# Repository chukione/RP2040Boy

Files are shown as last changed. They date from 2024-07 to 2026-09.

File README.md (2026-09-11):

# ~~Arduino~~RP2040boy
~~Official~~ ArduinoBoy port to RP2040 uC, its cheapear than a avr uC, it have so much more ram than a avr. The available boards come with megabytes of flash space, making ideal to use a oled display instead of the leds array.

On the breadboard photo, im using a transistor and a led, but is removed on the schematic because is a non sense. In original code (what i left untouched), the optoisolator is powered without condition on setup() 

USB midi with TynyUSB lib, and serial midi work.

At the moment, the only tested mode is mGB. LSJD midiout via usb is broken (serial must work, but its disabled.)

I normaly use linux, the dependencies and the pico toolchain is installed automacally on vscode with platformio extension, but on windows, you need to enable long paths on both git, and windows as described [here](https://arduino-pico.readthedocs.io/en/latest/platformio.html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). On arduino ide, you need to add the Earle Philhower core as described [here](https://learn.adafruit.com/rp2040-arduino-with-the-earlephilhower-core/installing-the-earlephilhower-core), also need to add the u8g2 library and the forty seven effects midi library and select the tinyusb usb stack on the menu.

rp4020boy_case
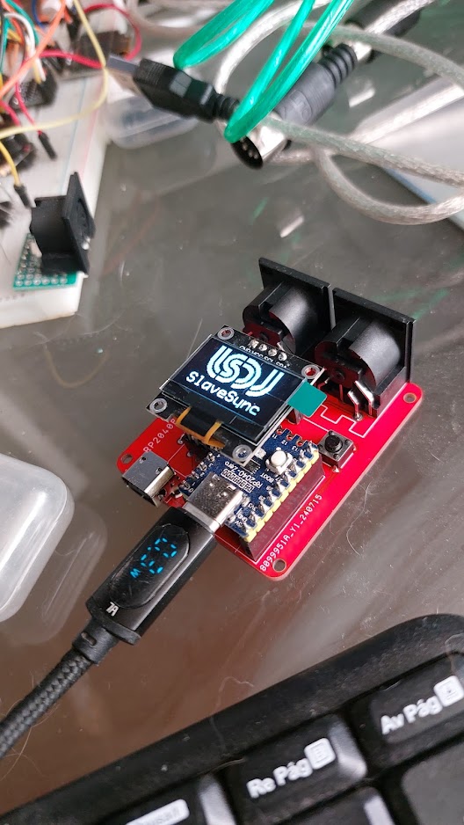
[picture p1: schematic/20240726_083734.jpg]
rp4020boy_pcb

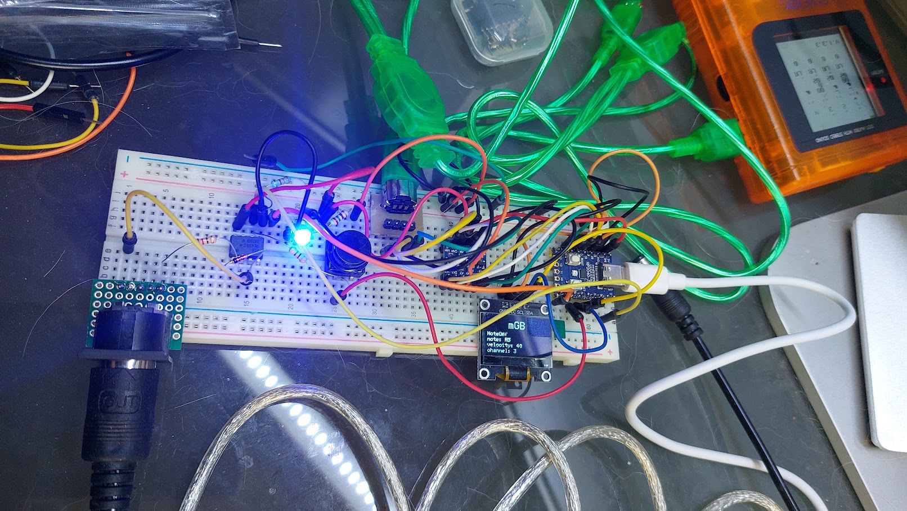
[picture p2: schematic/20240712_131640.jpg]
rp4020boy


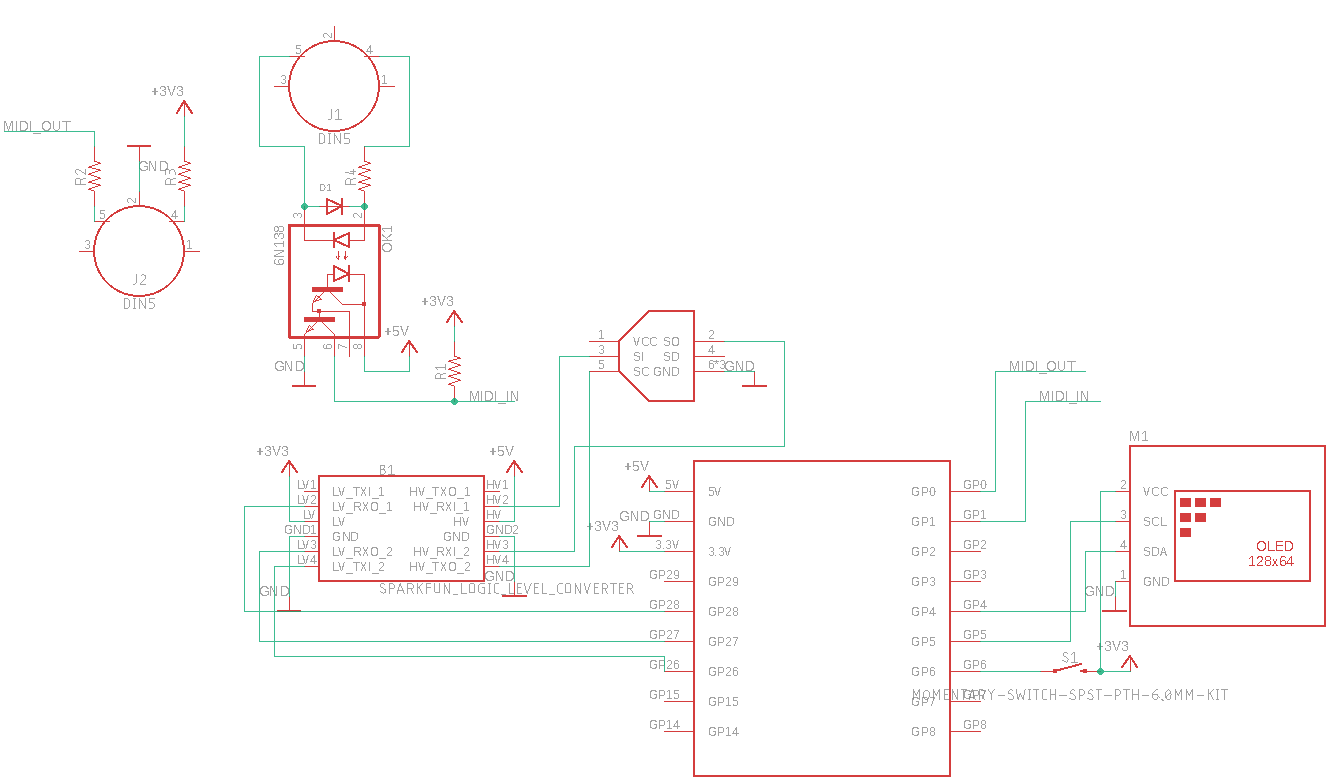
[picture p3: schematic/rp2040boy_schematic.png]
schematic


Repository for serial MIDI communication to the Nintendo Gameboy.



## About 
Arduinoboy is software for the [Arduino hardware platform](http://arduino.cc) that allows serial communication (MIDI) to the Nintendo Gameboy for music applications such as [LittleSoundDJ](http://littlesounddj.com), [Nanoloop.](http://www.nanoloop.com/), and [mGB](https://github.com/trash80/mGB)

## Current Features
* Affordable and easily accessible parts for assembly.
* Accurate MIDI Sync, Start and Stop commands.
* Push Button selector sets the sync/state modes [(7 modes available)](#modes-details)
* [mGB](https://github.com/trash80/mGB)
 Mode: Full MIDI in support across all Gameboy Channels, including a unique "poly" mode allows you to play your Game Boy like a synthesizer. 
* Midi Out Doubles as a Midi Thru
* "Filtering" data for only sync messages, no dedicated MIDI line required.
* Can be powered by the Game Boy's gamelink port.
* USB upgradeable via Arduino.
* Midi settings configurable using a Mac/PC editor built in Max.
* Tested and works with DMG (Original), Gameboy Color, and Advance/SP.

## Modes Details
#### Mode 1 - LSDJ as MIDI Slave Sync
Slave your Game Boy running [LittleSoundDJ](http://littlesounddj.com) to your midi sequencer or Digital audio workstation.  

You can send the arduinoboy midi notes to change sync resolution and start/stop the LSDJ sequencer.  

_LSDJ Slave Mode Midi Note Effects:_

* 48 - `C-2` Sends a Sequencer Start Command
* 49 - `C#2` Sends a Sequencer Stop Command
* 50 - `D-2` Toggles Normal Tempo 
* 51 - `D#2` Toggles 1/2 Tempo
* 52 - `E-2` Toggles 1/4 Tempo
* 53 - `F-2` Toggles 1/8 Tempo

Higher note values than these map LSDJ song position row offset on a Song Start.

In LSDJ the `sync` mode should be set to `Slave`
 
#### Mode 2 LSDJ as MIDI Master Sync. 

Send Midi sync with LSDJ as a midi clock master, LSDJ also sends a Midi Note on message that corresponds to the song row number on play.

In LSDJ the `sync` mode should be set to `Master`

#### Mode 3 LSDJ PC Keyboard mode.
This mode emulates the [PC Keyboard Mode](http://littlesounddj.wikia.com/wiki/PC_Keyboard_Interface) built into LSDJ, allowing you to control the following aspects of LSDJ: 

Features:

* The first octave controls M-U-T-E, 
* Cursor control (LSDJ Live mode only), 
* Table selection
* Table cue.

_PC Keyboard mode midi note map_

* 36 - `C-1` Mute Pu1 Off/On
* 37 - `C#1` Mute Pu2 Off/On
* 38 - `D-1` Mute Wav Off/On
* 39 - `D#1` Mute Noi Off/On
* 40 - `E-1` Livemode Cue Sequence
* 41 - `F-1` Livemode Cursor Up
* 42 - `F#1` Livemode Cursor Down
* 43 - `G-1` Livemode Cursor Left
* 44 - `G#1` Live mode Cursor Right
* 45 - `A-1` Table Up
* 46 - `A#1` Table Down
* 47 - `B-1` Cue Table
* 48+ - Notes from this note up will accept midi in from an external keyboard or sequencer and allow you to play the notes`C-2 to C-8`.  
* Midi Program Change messages will select from instrument table
* Default Midi channel is 16. You can set this in the top of the main source file in the archive, or via the [Max Pat editor](#max).

In LSDJ the `sync` mode should be set to `Keyboard`

#### Mode 4 MIDI to Nanoloop sync
Sync [Nanoloop.](http://www.nanoloop.com/) to external midi clock signals sent to the midi in.

In Nanoloop, the sync mode should be set to `slave`.

#### Mode 5 Full MIDI with mGB
[mGB](https://github.com/trash80/mGB) is a Gameboy cartridge program (You need a Flash Cart and Transfer hardware) That enables the Gameboy to act as a MIDI supported sound module that allows full control of the Game Boy sound hardware. 

It works with the old DMG Gameboy as well as GBC/GBA.

#### Mode 6 LSDJ MIDIMAP 
Lsdj will sync to incoming MIDI sync, and incoming MIDI notes are mapped to LSDJ's song row #. The currently selected row's MIDI note is displayed on the top right of the LSDJ screen, and incoming MIDI notes will also display the relative song row number in the same location.

In LSDJ the `sync` mode should be set to `MI.MAP`. 

*This requires a special version of LSDJ, which can be found in your account on the [LSDJ website](http://littlesounddj.com/lsd/latest/full_version/).*

#### Mode 7 LSDJ MIDIOUT
Each of the 4 gameboy channels send MIDI data on 4 midi channels by the use of effects commands:

* `Nxx` - Sends a MIDI Note - Absolute to the value placed in the effect. N00 sends note off, `N01`-`N6F` send midi notes 1 to 112.
* `Qxx` - Sends a [MIDI Note](http://www.electronics.dit.ie/staff/tscarff/Music_technology/midi/midi_note_numbers_for_octaves.htm) relative to the current channel's pitch. The effect value is a offset. so `Q0C` in `PU1` would send a note 1 octave higher than what `PU1` is currently playing. This is useful as a table command to track midi notes as normal notes in the sequencer.
* `Xxx` - Sends a MIDI CC - By default in Arduinoboy the high nibble selects a CC#, and the low nibble sends a value `0-F` to `0-127`. This can be changed to allow just 1 midi CC with a range of `00`-`6F`, or 7 CCs with scaled or unscaled values.
* `Yxx` - Sends a program/patch/preset change.

By default each channel of LSDJ is mapped to midi channels 1-4. For example note commands from PU1 will be sent to midi channel 1. 

In LSDJ the `sync` mode should be set to `Midiout`. 

*This requires a special version of LSDJ, which can be found in your account on the [LSDJ website](http://littlesounddj.com/lsd/latest/full_version/).*

## Max Editor
Editor gui
[The Arduinoboy Editor for Max](https://github.com/trash80/Arduinoboy/tree/master/Editor) for PC/OSX machines is a gui editor that allows you to edit the various global midi settings of your arduinoboy without editing or flashing code, over midi. It used to required the now deprecated Max Runtime, but you can also run it using a demo of [Cycling '74's Max application](https://cycling74.com/downloads/)

### Maxpat Settings
* `Midi In/Out`
Connect your arduinoboy to these ports on your system. Once it has connected, all the lights on your arduinoboy should flash in order, and the editor will show a green `Connected`.
* `Mode` 
Setting this will tell your arduinoboy what mode to boot into automatically. This is handy if you built your own arduinoboy and decided you wanted to skimp out on LEDs and a button.
* `LSDJ Slave Mode settings` - The midi channel LSDJ slave mode will receive its commands on.
* `LSDJ Master Mode settings` - The midi channel LSDJ Master mode will send its midi notes mapped to row number on.
* `Keyboard Mode settings` - What channel LSDJ will look for its keyboard mode midi commands. No idea what compatibility mode does.
* `mGB midi settings` - Map each incoming midi channel to a specific Gameboy channel in mGB.
* `LSDJ Livesync/Livemap settings` - The midi channel Livesync/Livemap will listen to incoming midi commands from.
* `LSDJ Midiout settings` - Here you can set the following:
	* `Note midi channel` -  The channel each LSDJ channel will send it's midi note commands on.
	* `CC midi channel` -  The channel each LSDJ channel will send it's Continuous Controller commands on.
	* `CC 0` - The initial CC each channel will send. The type of data it will send is based on the next setting.
	* `CC Mode` - Game Boys have limitations! You can either have arduinoboy send one CC with many values, or 7 with limited 8bit values. By default in Arduinoboy the high nibble selects a CC#, and the low nibble sends a value [0-F] to [0-127]. This can be changed to allow just 1 midi CC with a range of 00-6F, or 7 CCs with scaled or unscaled values.
	* `CC Scaling ` - Set wether the 7 CCs are scaled or unscaled.

## Future Features & wishlist
  * Build instructions, and a Arduino Shield

## How To build an Arduinoboy



* [Build Photos](http://flickr.com/photos/trash80/2316803175/in/set-72157604068871573/)
* [Old version (Pre 1.1.0)](http://trash80.net/junkfood/arduinoboy/arduinoboy-schem-v.0.9.8-r1.png)

### Video Demos

  * [Keyboard Mode Test](http://youtube.com/watch?v=TnLUuvc78XY)
  * [Sync Demos](http://youtube.com/watch?v=iVmhy-Lo7BI)
  * [Arduino inside of Gameboy DMG](http://youtube.com/watch?v=VwrMuOA0VnY)
  * [mGB Example & Arduinoboy build into a DMG](http://vimeo.com/1853931)
  * [PDF explores mGB with a MIDI guitar](http://www.youtube.com/watch?v=HAU9MzZ2qeE)

## Thanks To
  * [Arduino](http://arduino.cc)
  * [Nitro2k01](http://blog.gg8.se/wordpress/) for ASM help with mGB 
  * [GWEM](http://www.preromanbritain.com/gwem/lsdj_midi/g33k.html) g33k page
  * [Midines](http://wayfar.net) Thanks for the help x|k!
  * [firestARTer](http://www.firestarter-music.de) help with keyboard & Midi handling information. 
  * [Gijs Gieskes](http://gieskes.nl) Found source code that gave insight into Nanoloop sync
  * [Little Sound DJ](http://littlesounddj.com)
  * [http://devrs.com/gb](http://devrs.com/gb) Madcatz PC link port for gb serial specs
  * [http://chipmusic.org](http://chipmusic.org) For all things Chipmusic.

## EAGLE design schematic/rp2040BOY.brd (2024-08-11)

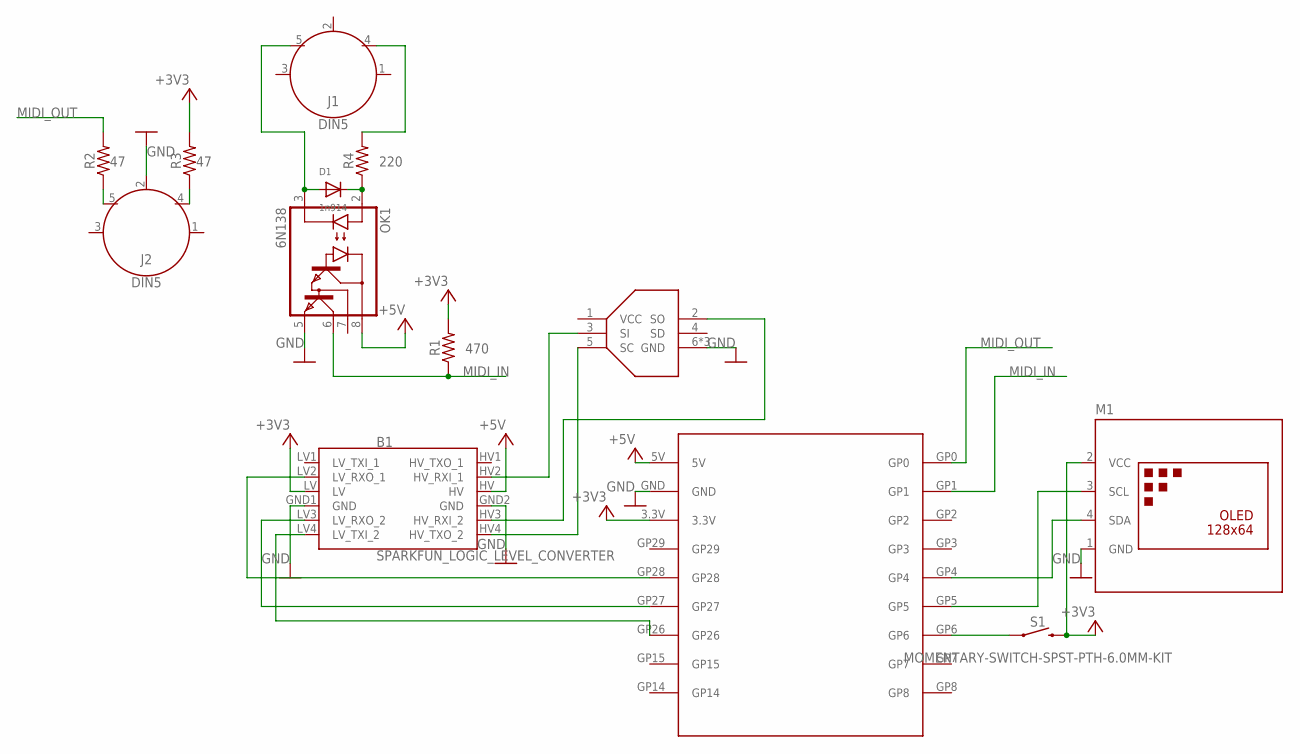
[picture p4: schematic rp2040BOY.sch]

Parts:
B1: SPARKFUN_LOGIC_LEVEL_CONVERTER
D1: 1n914; DO-1N4148
J1, J2: DIN5; DIN5-RA-PTH
M1: OLED-128X64-I2C-NH; DISPLAY-OLED-128X64-I2C_NH
OK1: 6N138; DIL08
R1: 470; AXIAL-0.3
R2, R3: 47; AXIAL-0.3
R4: 220; AXIAL-0.3
S1: MOMENTARY-SWITCH-SPST-PTH-6.0MM-KIT; TACTILE_SWITCH_PTH_6.0MM_KIT
U$1: GBC_LINK_CONN; GBC
U$2: RP2040-ZERO-ROUND; RP2040-ZERO_O

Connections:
+3V3: B1.LV, M1.2 (VCC), R1.P$2 (2), R3.P$2 (2), S1.3 (2), U$2.3.3V
+5V: B1.HV, OK1.8 (VCC), U$2.5V
GND: B1.GND1 (GND), B1.GND2 (GND), J2.2, M1.1 (GND), OK1.5 (GND), U$1.6 (GND), U$1.P$7 (GND), U$1.P$8 (GND), U$2.GND
MIDI_IN: OK1.6 (VO), R1.P$1 (1), U$2.GP1
MIDI_OUT: R2.P$2 (2), U$2.GP0
unnamed: B1.LV4 (LV_TXI_2), U$2.GP26
unnamed: B1.LV3 (LV_RXO_2), U$2.GP27
unnamed: B1.LV2 (LV_RXO_1), U$2.GP28
unnamed: B1.HV3 (HV_RXI_2), U$1.2 (SO)
unnamed: B1.HV2 (HV_RXI_1), U$1.3 (SI)
unnamed: B1.HV4 (HV_TXO_2), U$1.5 (SC)
unnamed: S1.1, U$2.GP6
unnamed: M1.4 (SDA), U$2.GP4
unnamed: M1.3 (SCL), U$2.GP5
unnamed: D1.A, J1.5, OK1.3 (C)
unnamed: D1.C, OK1.2 (A), R4.P$1 (1)
unnamed: J2.5, R2.P$1 (1)
unnamed: J2.4, R3.P$1 (1)
unnamed: J1.4, R4.P$2 (2)

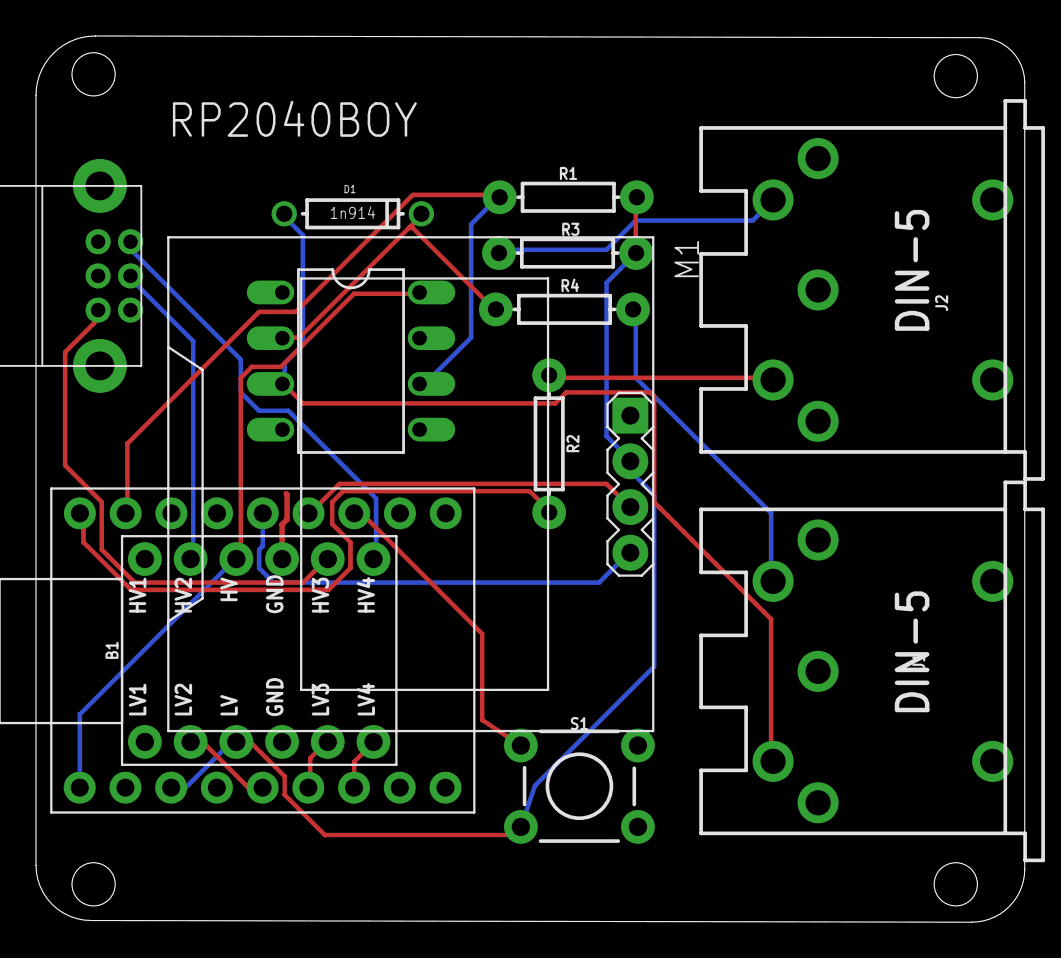
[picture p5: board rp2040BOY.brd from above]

Board: 2 copper layers, 54.9 x 49.2 mm, 13 parts (0 on the bottom side), 19 nets.

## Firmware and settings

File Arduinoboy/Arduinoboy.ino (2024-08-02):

/***************************************************************************
 ***************************************************************************
 *                         __      _             __                        *
 *         ____ __________/ /_  __(_)___  ____  / /_  ____  __  __         *
 *        / __ `/ ___/ __  / / / / / __ \/ __ \/ __ \/ __ \/ / / /         *
 *       / /_/ / /  / /_/ / /_/ / / / / / /_/ / /_/ / /_/ / /_/ /          *
 *       \__,_/_/   \__,_/\__,_/_/_/ /_/\____/_.___/\____/\__, /           *
 *                                                       /____/            *
 *                                                                         *
 ***************************************************************************
 ***************************************************************************
 *                                                                         *
 * Version: 1.3.4                                                          *
 * Date:    May 19 2020                                                    *
 * Name:    Timothy Lamb                                                   *
 * Email:   trash80@gmail.com                                              *
 *                                                                         *
 ***************************************************************************
 ***************************************************************************
 *                                                                         *
 * NOTICE NOTICE NOTICE NOTICE NOTICE NOTICE NOTICE NOTICE NOTICE NOTICE   *
 *                                                                         *
 *  https://github.com/trash80/Arduinoboy                                  *
 *                                                                         *
 *   Arduino pin settings:  (Layout is final)                              *
 *     - 6 LEDS on pins 8 to 13                                            *
 *     - Push button on pin 3 (for selecting mode)                         *
 *     - MIDI Opto-isolator power on pin 4                                 *
 *     - Gameboy Clock line on analog in pin 0                             *
 *     - Gameboy Serial Data input on analog in pin 1                      *
 *     - Serial Data from gameboy on analog in pin 2                       *
 *                                                                         *
 *   Teensy pin settings:                                                  *
 *     - 6 LEDS on pins 23,22,21,20,4,13                                   *
 *     - Push button on pin 2 (for selecting mode)                         *
 *     - MIDI Opto-isolator power connected to +3v                         *
 *     - Gameboy Clock line on pin 16                                      *
 *     - Gameboy Serial Data input on analog in pin 17                     *
 *     - Serial Data from gameboy on analog in pin 18                      *
 *                                                                         *
 *   Teensy USB MIDI is supported                                          *
 *   Teensy LC should work but untested                                    *
 *                                                                         *
 * Program Information:                                                    *
 *    LSDJ Slave Mode Midi Note Effects:                                   *
 *      48 - C-2 Sends a Sequencer Start Command                           *
 *      49 - C#2 Sends a Sequencer Stop Command                            *
 *      50 - D-2 Toggles Normal Tempo                                      *
 *      51 - D#2 Toggles 1/2 Tempo                                         *
 *      52 - E-2 Toggles 1/4 Tempo                                         *
 *      53 - F-2 Toggles 1/8 Tempo                                         *
 *                                                                         *
 *    LSDJ Keyboard Mode:                                                  *
 *      48 - C-2 Mute Pu1 Off/On                                           *
 *      49 - C#2 Mute Pu2 Off/On                                           *
 *      50 - D-2 Mute Wav Off/On                                           *
 *      51 - D#2 Mute Noi Off/On                                           *
 *      52 - E-2 Livemode Cue Sequence                                     *
 *      53 - F-2 Livemode Cursor Up                                        *
 *      54 - F#2 Livemode Cursor Down                                      *
 *      55 - G-2 Livemode Cursor Left                                      *
 *      56 - G#2 Livemode Cursor Right                                     *
 *      57 - A-2 Table Up                                                  *
 *      58 - A#2 Table Down                                                *
 *      59 - B-2 Cue Table                                                 *
 *      60 - C-3 to C-8 Notes!                                             *
 *      Prgram Change to select from instrument table                      *
 *                                                                         *
 ***************************************************************************/
/***************************************************************************
 *                                                                         *
 *   This program is free software; you can redistribute it and/or modify  *
 *   it under the terms of the GNU General Public License as published by  *
 *   the Free Software Foundation; either version 2 of the License, or     *
 *   (at your option) any later version.                                   *
 *                                                                         *
 ***************************************************************************/
#define OLED
#define OLED_GFX

#define MEM_MAX 65
#define NUMBER_OF_MODES 7 // Right now there are 7 modes, Might be more in the future

//!!! do not edit these, they are the position in EEPROM memory that contain the value of each stored setting
#define MEM_CHECK 0
#define MEM_VERSION_FIRST 1
#define MEM_VERSION_SECOND 2
#define MEM_FORCE_MODE 4
#define MEM_MODE 5
#define MEM_LSDJSLAVE_MIDI_CH 6
#define MEM_LSDJMASTER_MIDI_CH 7
#define MEM_KEYBD_CH 8
#define MEM_KEYBD_COMPAT_MODE 9
#define MEM_KEYBD_CH_TO_INST 10
#define MEM_MIDIOUT_NOTE_CH 11
#define MEM_MIDIOUT_CC_CH 15
#define MEM_MIDIOUT_CC_MODE 19
#define MEM_MIDIOUT_CC_SCALING 23
#define MEM_MIDIOUT_CC_NUMBERS 27
#define MEM_MGB_CH 55
#define MEM_LIVEMAP_CH 60
#define MEM_MIDIOUT_BIT_DELAY 61
#define MEM_MIDIOUT_BYTE_DELAY 63

/***************************************************************************
 * User Settings
 ***************************************************************************/

#ifdef OLED
#ifndef OLED_GFX
#include <U8x8lib.h>
U8X8_SSD1306_128X64_NONAME_HW_I2C u8x8(U8X8_PIN_NONE);
#else
#include <U8g2lib.h>
#ifdef ARDUINO_ARCH_RP2040
U8G2_SSD1306_128X64_NONAME_F_HW_I2C u8g2(U8G2_R2, U8X8_PIN_NONE);
#include "lsdj.h"
#include "nanoloop.h"
#include "mgb.h"
#include "din5.h"
#include "usb.h"
#else
U8G2_SSD1306_128X64_NONAME_2_HW_I2C u8g2(U8G2_R0, U8X8_PIN_NONE);
#endif
#include "gfx.h" //splash image
#endif
#endif

boolean usbMode = false; // to use usb for serial communication as oppose to MIDI - sets baud rate to 38400

byte defaultMemoryMap[MEM_MAX] = {
    0x7F, 0x01, 0x03, 0x7F, // memory init check
    0x00,                   // force mode (forces lsdj to be sl)
    0x00,                   // mode
    15,                     // sync effects midi channel (0-15 = 1-16)
    15,                     // masterNotePositionMidiChannel - LSDJ in master mode will send its song position on the start button via midi note. (0-15 = 1-16)
    15,                     // keyboardInstrumentMidiChannel - midi channel for keyboard instruments in lsdj. (0-15 = 1-16)
    1,                      // Keyboard Compatability Mode
    1,                      // Set to true if you want to have midi channel set the instrument number / doesnt do anything anymore
    0, 1, 2, 3,             // midiOutNoteMessageChannels - midi channels for lsdj midi out note messages Default: channels 1,2,3,4
    0, 1, 2, 3,             // midiOutCCMessageChannels - midi channels for lsdj midi out CC messages Default: channels 1,2,3,4
    1, 1, 1, 1,             // midiOutCCMode - CC Mode, 0=use 1 midi CC, with the range of 00-6F, 1=uses 7 midi CCs with the
                            // range of 0-F (the command's first digit would be the CC#), either way the value is scaled to 0-127 on output
    1, 1, 1, 1,             // midiOutCCScaling - CC Scaling- Setting to 1 scales the CC value range to 0-127 as oppose to lsdj's incomming 00-6F (0-112) or 0-F (0-15)
    1, 2, 3, 7, 10, 11, 12, // pu1: midiOutCCMessageNumbers - CC numbers for lsdj midi out, if CCMode is 1, all 7 ccs are used per channel at the cost of a limited resolution of 0-F
    1, 2, 3, 7, 10, 11, 12, // pu2
    1, 2, 3, 7, 10, 11, 12, // wav
    1, 2, 3, 7, 10, 11, 12, // noi
    0, 1, 2, 3, 4,          // mGB midi channels (0-15 = 1-16)
    0,                      // sync map midi channel start (0-15 = 1-16) (for song rows 0x80 to 0xFF it's this channel plus 1)
    80, 1,                  // midiout bit check delay & bit check delay multiplier
    0, 0                    // midiout byte received delay & byte received delay multiplier
};
byte memory[MEM_MAX];

/***************************************************************************
 * Lets Assign our Arduino Pins .....
 ***************************************************************************/

/***************************************************************************
 * Teensy 3.2, Teensy LC
 *
 * Notes on Teensy: Pins are not the same as in the schematic, the mapping is below.
 * Feel free to change, all related config in is this block.
 * Be sure to compile
 ***************************************************************************/
#if defined(__MK20DX256__) || defined(__MK20DX128__) || defined(__MKL26Z64__)
#define USE_TEENSY 1
#define USE_USB 1
#include <MIDI.h>

#if defined(__MKL26Z64__)
#define GB_SET(bit_cl, bit_out, bit_in) GPIOB_PDOR = ((bit_in << 3) | (bit_out << 1) | bit_cl)
#else
#define GB_SET(bit_cl, bit_out, bit_in) GPIOB_PDOR = (GPIOB_PDIR & 0xfffffff4) | ((bit_in << 3) | (bit_out << 1) | bit_cl)
#endif

int pinGBClock = 16;                     // Analog In 0 - clock out to gameboy
int pinGBSerialOut = 17;                 // Analog In 1 - serial data to gameboy
int pinGBSerialIn = 18;                  // Analog In 2 - serial data from gameboy
int pinMidiInputPower = 0;               // Not used!
int pinStatusLed = 13;                   // Status LED
int pinLeds[] = {23, 22, 21, 20, 4, 13}; // LED Pins
int pinButtonMode = 2;                   // toggle button for selecting the mode

HardwareSerial *serial = &Serial1;

/***************************************************************************
 * Arduino Leonardo/Yún/Micro (ATmega32U4)
 ***************************************************************************/
#elif defined(__AVR_ATmega32U4__)
#define USE_LEONARDO
#include <MIDIUSB.h>

#define GB_SET(bit_cl, bit_out, bit_in) PORTF = (PINF & B00011111) | ((bit_cl << 7) | ((bit_out) << 6) | ((bit_in) << 5))
// ^ The reason for not using digitalWrite is to allign clock and data pins for the GB shift reg.
// Pin distribution comes from official Arduino Leonardo documentation

int pinGBClock = A0;                // Analog In 0 - clock out to gameboy
int pinGBSerialOut = A1;            // Analog In 1 - serial data to gameboy
int pinGBSerialIn = A2;             // Analog In 2 - serial data from gameboy
int pinMidiInputPower = 16;         // power pin for midi input opto-isolator
int pinStatusLed = 10;              // Status LED
int pinLeds[] = {4, 5, 6, 7, 8, 9}; // LED Pins
int pinButtonMode = 14;             // toggle button for selecting the mode

HardwareSerial *serial = &Serial1;

/***************************************************************************
 * Raspberry pi pico (rp2040)
 ***************************************************************************/
#elif defined(ARDUINO_ARCH_RP2040)
#define USE_PICO
#ifdef OLED
#include <Wire.h>
#endif

#include <Adafruit_TinyUSB.h>
#include <MIDI.h>

// USB MIDI object
Adafruit_USBD_MIDI usb_midi;
// Create a new instance of the Arduino MIDI Library,
// and attach usb_midi as the transport.
MIDI_CREATE_INSTANCE(Adafruit_USBD_MIDI, usb_midi, usbMIDI);

#define GB_SET(bit_cl, bit_out, bit_in) \
  digitalWriteFast(D26, bit_cl);        \
  digitalWriteFast(D27, bit_out);       \
  digitalWriteFast(D28, bit_in);
// ^ The reason for not using digitalWrite is to allign clock and data pins for the GB shift reg.

int pinGBClock = A0;        // Analog In 0 - clock out to gameboy
int pinGBSerialOut = A1;    // Analog In 1 - serial data to gameboy
int pinGBSerialIn = A2;     // Analog In 2 - serial data from gameboy
int pinMidiInputPower = D8; // power pin for midi input opto-isolator
// int pinStatusLed = D17;              // Status LED
// int pinLeds[] = {D25, D24, D23, D22, D21, D20}; // LED Pins
int pinButtonMode = D6; // toggle button for selecting the mode

HardwareSerial *serial = &Serial1;

/***************************************************************************
 * Arduino Due (ATmSAM3X8E)
 ***************************************************************************/
#elif defined(__SAM3X8E__)
#define USE_DUE

#define USE_LEONARDO
#include <MIDIUSB.h>
#include <digitalWriteFast.h>

#define GB_SET(bit_cl, bit_out, bit_in) \
  digitalWriteFast(A0, bit_cl);         \
  digitalWriteFast(A1, bit_out);        \
  digitalWriteFast(A2, bit_in);
// ^ The reason for not using digitalWrite is to allign clock and data pins for the GB shift reg.

int pinGBClock = A0;                    // Analog In 0 - clock out to gameboy
int pinGBSerialOut = A1;                // Analog In 1 - serial data to gameboy
int pinGBSerialIn = A2;                 // Analog In 2 - serial data from gameboy
int pinMidiInputPower = 4;              // power pin for midi input opto-isolator
int pinStatusLed = 13;                  // Status LED
int pinLeds[] = {12, 11, 10, 9, 8, 13}; // LED Pins
int pinButtonMode = 3;                  // toggle button for selecting the mode

HardwareSerial *serial = &Serial;

/***************************************************************************
 * Arduino UNO/Ethernet/Nano (ATmega328), Arduino UNO Wifi (ATmega4809) or Mega 2560 (ATmega2560/ATmega1280) (assumed)
 ***************************************************************************/
#else

#if defined(__AVR_ATmega1280__) || defined(__AVR_ATmega2560__)
#define GB_SET(bit_cl, bit_out, bit_in) PORTF = (PINF & B11111000) | ((bit_in << 2) | ((bit_out) << 1) | bit_cl)
#elif defined(__AVR_ATmega4809__)
#define GB_SET(bit_cl, bit_out, bit_in) PORTD = (PIND & B11111000) | ((bit_in << 2) | ((bit_out) << 1) | bit_cl)
#else
#define GB_SET(bit_cl, bit_out, bit_in) PORTC = (PINC & B11111000) | ((bit_in << 2) | ((bit_out) << 1) | bit_cl)
#endif
// ^ The reason for not using digitalWrite is to allign clock and data pins for the GB shift reg.

int pinGBClock = A0;                    // Analog In 0 - clock out to gameboy
int pinGBSerialOut = A1;                // Analog In 1 - serial data to gameboy
int pinGBSerialIn = A2;                 // Analog In 2 - serial data from gameboy
int pinMidiInputPower = 4;              // power pin for midi input opto-isolator
int pinStatusLed = 13;                  // Status LED
int pinLeds[] = {12, 11, 10, 9, 8, 13}; // LED Pins
int pinButtonMode = 3;                  // toggle button for selecting the mode

HardwareSerial *serial = &Serial;

#endif

/***************************************************************************
 * Memory
 ***************************************************************************/
#if !defined(USE_DUE) && !defined(USE_PICO)
#include <EEPROM.h>
boolean alwaysUseDefaultSettings = false; // set to true to always use the settings below, else they are pulled from memory for the software editor
#else
boolean alwaysUseDefaultSettings = true; // set to true to always use the default settings, in pico board is necessary as it doesn't have EEPROM
#endif

int eepromMemoryByte = 0; // Location of where to store settings from mem

/***************************************************************************
 * Sysex Settings & vars
 ***************************************************************************/

boolean sysexReceiveMode = 0;
boolean sysexProgrammingMode = 0;
boolean sysexProgrammingWaiting = 0;
boolean sysexProgrammingConnected = 0;

unsigned long sysexProgrammerWaitTime = 2000; // 2 seconds
unsigned long sysexProgrammerCallTime = 1000; // 1 second
unsigned long sysexProgrammerLastResponse = 0;
unsigned long sysexProgrammerLastSent = 0;

byte sysexManufacturerId = 0x69; // har har harrrrr :)
int sysexPosition;
byte sysexData[128];
byte longestSysexMessage = 128;

int midioutBitDelay = 0;
int midioutByteDelay = 0;

/***************************************************************************
 * Switches and states
 ***************************************************************************/
boolean sequencerStarted = false; // Sequencer has Started
boolean midiSyncEffectsTime = false;
boolean midiNoteOnMode = false;
boolean midiNoteOffMode = false;
boolean midiProgramChange = false;
boolean midiAddressMode = false;
boolean midiValueMode = false;

int midiOutLastNote[4] = {-1, -1, -1, -1};

boolean statusLedIsOn = false;
boolean statusLedBlink = false;

boolean nanoState = false;
boolean nanoSkipSync = false;

int buttonDepressed;
int buttonState;
unsigned long int buttonProgrammerWaitTime = 2000; // 2 whole seconds
unsigned long int buttonTime;

boolean blinkSwitch[6];
unsigned long int blinkSwitchTime[6];
uint8_t switchLight = 0;

uint16_t blinkMaxCount = 1000;

unsigned long midioutNoteTimer[4];
byte midioutNoteHold[4][4];
byte midioutNoteHoldCounter[4];
int midioutNoteTimerThreshold = 10;

/***************************************************************************
 * Counter vars
 ***************************************************************************/
int countLSDJTicks = 0; // for loop int (we need to cycle 8 pulses)
int countSyncTime = 0;
int countSyncLightTime = 0;
int countSyncSteps = 0;
int countSyncPulse = 0;
int countGbClockTicks = 0;
int countClockPause = 0;
int countIncommingMidiByte = 0;
int countStatusLedOn = 0;
unsigned int waitClock = 0;

int miscLastLed;
unsigned long int miscLedTime;
unsigned long int miscLedMaxTime;

/***************************************************************************
 * Inbound Data Placeholders
 ***************************************************************************/
byte incomingMidiByte; // incomming midi message
byte readgbClockLine;
byte readGbSerialIn;
byte bit;
byte midiData[] = {0, 0, 0};
byte lastMidiData[] = {0, 0, 0};

int incomingMidiNote = 0;
int incomingMidiVel = 0;
byte readToggleMode;
byte serialWriteBuffer[256];
byte midiDefaultStartOffset;
int writePosition = 0;
int readPosition = 0;
int lastMode = 0; // Stores the last selected mode for leds.

byte midiSyncByte;
byte midiSyncByteLast;

byte midiStatusType;
byte midiStatusChannel;

/***************************************************************************
 * LSDJ Keyboard mode settings
 ***************************************************************************/
byte keyboardNotes[] = {0x1A, 0x1B, 0x22, 0x23, 0x21, 0x2A, 0x34, 0x32, 0x33, 0x31, 0x3B, 0x3A,
                        0x15, 0x1E, 0x1D, 0x26, 0x24, 0x2D, 0x2E, 0x2C, 0x36, 0x35, 0x3D, 0x3C};
byte keyboardOctDn = 0x05;
byte keyboardOctUp = 0x06;

byte keyboardInsDn = 0x04;
byte keyboardInsUp = 0x0C;

byte keyboardTblDn = 0x03;
byte keyboardTblUp = 0x0B;

byte keyboardTblCue = 0x29;
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
void loop()
{
  setMode();
  switchMode();
}
#ifdef USE_PICO // draw data with core2 on rp2040 because u8g2 draw too slow on the i2c display
#include "midi_values.h"
void setup1()
{
}
void loop1()
{
  if (memory[MEM_MODE] == 4)
  { // for now only draw info for mGB mode

    while (uint32_t mididata = rp2040.fifo.pop())
    {
      byte message_type = (mididata & 0x000000ff);
      byte channel = (mididata & 0x0000ff00) >> 8;
      byte data1 = (mididata & 0x00ff0000) >> 16;
      byte data2 = (mididata & 0xff000000) >> 24;

      u8g2.clearBuffer();
      u8g2.setFont(u8g2_font_profont22_mf);
      switch (memory[MEM_MODE])
      {
      case 0:
        u8g2.setCursor(5, 20);
        u8g2.print("LSDJ SLV");
        break;
      case 1:
        u8g2.setCursor(4, 20);
        u8g2.print("LSDJ MSTR");
        break;
      case 2:
        u8g2.setCursor(5, 20);
        u8g2.print("LSDJ KBR");
        break;
      case 3:
        u8g2.setCursor(4, 20);
        u8g2.print("NANOLOOP");
        break;
      case 4:
        u8g2.setCursor(45, 20);
        u8g2.print("mGB");
        break;
      case 5:
        u8g2.print("LSDJ MAP");
        u8g2.setCursor(5, 20);
        break;
      case 6:
        u8g2.print("LSDJ MIDI");
        u8g2.setCursor(5, 20);
        break;
      }
      if (midi_mode == 0)
      {
        u8g2.drawXBMP(105, 2, din5_width, din5_height, din5_bits);
      }
      else if (midi_mode == 1)
      {
        u8g2.drawXBMP(89, 2, usb_width, usb_height, usb_bits);
      }
      u8g2.setFont(u8g2_font_6x12_tf);
      u8g2.setCursor(1, 34);
      u8g2.print(messagesTypes[message_type].c_str());
      u8g2.setCursor(1, 44);
      u8g2.print("note: ");
      u8g2.print(notes[data1]);
      u8g2.setCursor(1, 54);
      u8g2.print("velocity: ");
      u8g2.print(data2, HEX);
      u8g2.setCursor(1, 64);
      u8g2.print("channel: ");
      u8g2.print(channel, DEC);
      u8g2.sendBuffer();
    }
  }
}
#endif

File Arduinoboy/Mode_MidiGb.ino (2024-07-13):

/**************************************************************************
 * Name:    Timothy Lamb                                                  *
 * Email:   trash80@gmail.com                                             *
 ***************************************************************************/
/***************************************************************************
 *                                                                         *
 *   This program is free software; you can redistribute it and/or modify  *
 *   it under the terms of the GNU General Public License as published by  *
 *   the Free Software Foundation; either version 2 of the License, or     *
 *   (at your option) any later version.                                   *
 *                                                                         *
 ***************************************************************************/

void modeMidiGbSetup()
{
#ifndef USE_PICO
  digitalWrite(pinStatusLed, LOW);
#endif
  pinMode(pinGBClock, OUTPUT);
  digitalWrite(pinGBClock, HIGH);

#if defined(USE_TEENSY)
  usbMIDI.setHandleRealTimeSystem(NULL);
#endif

  blinkMaxCount = 1000;
  modeMidiGb();
}

void modeMidiGb()
{
  boolean sendByte = false;
  byte message_type;
  byte channel;
  byte first_byte;
  byte second_byte;
  while (1)
  { // Loop foreverrrr
    modeMidiGbUsbMidiReceive();

    if (serial->available())
    {
      midi_mode = 0;                     // If MIDI is sending
      incomingMidiByte = serial->read(); // Get the byte sent from MIDI

      if (!checkForProgrammerSysex(incomingMidiByte) && !usbMode)
        serial->write(incomingMidiByte); // Echo the Byte to MIDI Output

      if (incomingMidiByte & 0x80)
      {
        switch (incomingMidiByte & 0xF0)
        {
        case 0xF0: // system message type
          midiValueMode = false;
          break;
        default:
          sendByte = false;
          midiStatusChannel = incomingMidiByte & 0x0F; // channel
          midiStatusType = incomingMidiByte & 0xF0;
          if (midiStatusChannel == memory[MEM_MGB_CH])
          {
            midiData[0] = midiStatusType;
            sendByte = true;
          }
          else if (midiStatusChannel == memory[MEM_MGB_CH + 1])
          {
            midiData[0] = midiStatusType + 1;
            sendByte = true;
          }
          else if (midiStatusChannel == memory[MEM_MGB_CH + 2])
          {
            midiData[0] = midiStatusType + 2;
            sendByte = true;
          }
          else if (midiStatusChannel == memory[MEM_MGB_CH + 3])
          {
            midiData[0] = midiStatusType + 3;
            sendByte = true;
          }
          else if (midiStatusChannel == memory[MEM_MGB_CH + 4])
          {
            midiData[0] = midiStatusType + 4;
            sendByte = true;
          }
          else
          {
            midiValueMode = false;
            midiAddressMode = false;
          }
          if (sendByte)
          {
#ifndef USE_PICO
            statusLedOn();
#else
            message_type = midiStatusType;
            channel = midiStatusChannel;
#endif
            sendByteToGameboy(midiData[0]);
            delayMicroseconds(GB_MIDI_DELAY);
            midiValueMode = false;
            midiAddressMode = true;
          }
          break;
        }
      }
      else if (midiAddressMode)
      {
        midiAddressMode = false;
        midiValueMode = true;
        midiData[1] = incomingMidiByte;
        first_byte = midiData[1];
        sendByteToGameboy(midiData[1]);
        delayMicroseconds(GB_MIDI_DELAY);
      }
      else if (midiValueMode)
      {
        midiData[2] = incomingMidiByte;
        second_byte = midiData[2];
        midiAddressMode = true;
        midiValueMode = false;

        sendByteToGameboy(midiData[2]);
        delayMicroseconds(GB_MIDI_DELAY);
#ifndef USE_PICO
        statusLedOn();
        blinkLight(midiData[0], midiData[2]);
#else
        uint32_t mididata = (uint32_t)message_type | ((uint32_t)channel << 8) | ((uint32_t)first_byte << 16) | ((uint32_t)second_byte << 24);
        rp2040.fifo.push_nb(mididata);
#endif
      }
    }
    else
    {
      setMode(); // Check if mode button was depressed
#ifndef USE_PICO
      updateBlinkLights();
      updateStatusLed();
#endif
    }
  }
}

/*
sendByteToGameboy does what it says. yay magic
*/
void sendByteToGameboy(byte send_byte)
{
  for (countLSDJTicks = 0; countLSDJTicks != 8; countLSDJTicks++)
  { // we are going to send 8 bits, so do a loop 8 times
    if (send_byte & 0x80)
    {
      GB_SET(0, 1, 0);
#ifdef USE_PICO
      delayMicroseconds(1);
#endif
      GB_SET(1, 1, 0);
    }
    else
    {
      GB_SET(0, 0, 0);
#ifdef USE_PICO
      delayMicroseconds(1);
#endif
      GB_SET(1, 0, 0);
    }

#if defined(F_CPU) && (F_CPU > 24000000)
    // Delays for Teensy etc where CPU speed might be clocked too fast for cable & shift register on gameboy.
    delayMicroseconds(1);
#endif
    send_byte <<= 1;
  }
}
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

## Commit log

2024-07-05 LSDJ midiout broken (commented)
    [Arduinoboy.ino, Led_Functions.ino, Mode.ino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]
2024-07-12 schematic updated
2024-07-13 removed old schematic without serial midi
2024-08-02 fixed miditype cast on lsdj midiout
    [Arduinoboy.ino, Mode_LSDJ_Midiout.ino]
2024-08-11 eagle files added
    [rp2040BOY.brd, rp2040BOY.sch]

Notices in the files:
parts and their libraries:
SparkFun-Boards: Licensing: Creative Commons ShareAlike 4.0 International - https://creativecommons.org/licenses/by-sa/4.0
